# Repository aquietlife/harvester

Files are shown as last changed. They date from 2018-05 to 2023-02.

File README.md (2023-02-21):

# Harvester

Harvester in front of Pink Flowers

Harvester on grass

Harvester Profile

The Harvester is a hand-held, portable live sampler that lets you make music with everyday sounds. With the instrument, you are able to capture sounds around you (your voice, another musical instrument, environmental noises etc.). The instrument provides an interface that lets you play back the sampled sound based around a musical, pentatonic scale. This allows for a wildly expressive sonic palette that can be used for musical performance and sound art installations.

## Features

* Completely open-source software and hardware

* Audio I/O through onboard microphones, built-in speaker, and 1/4" output

* Gyroscope for 3-axis sensor input for affecting audio output

* Eight buttons for sample playbaack

* Recording button for sampling

* Looper button for simple looping

* Rechargable LiPo battery (completely portable and battery-powered!)

* Supports wall power/charging as well

## Videos

[Video of Harvester playing in snow](http://aquiet.life/assets/objects/harvester/harvester_snow.mov)

[Video of Harvester playing with gyroscope](https://drive.google.com/file/d/1DpVXfMJ-ruTxa6ZWckGBipXadZL-0WjP/view?usp=sharing)

[Video of Harvester playing in the Everglades](https://drive.google.com/file/d/1D1tRrY7IDSK8U0TIqJ7yX_h4CNaE4mdh/view?usp=share_link)

## Parts

A list of parts and costs can be found on this [Google Sheet](https://docs.google.com/spreadsheets/d/1hDYdzhToesEgNGzxmREglWhK1RFRyOljPsczHniATDo/edit?usp=sharing)

## Installation Instructions

### Solder up Harvester hat

* Full documentation TBD; The board itself has layouts for where compoenents should go!

### Install Raspian for Raspberry Pi

* Download the latest version of Raspian here: https://www.raspberrypi.org/downloads/raspbian/

* Install Raspian to your SD card. On OSX, you can use these instrucitons: https://www.raspberrypi.org/documentation/installation/installing-images/mac.md

* Whle the SD card is still connected, create a file called "ssh" in the boot directory of the card to enable SSH, e.g.:

`touch /Volumes/boot/ssh`

* Also, create a file called wpa_supplicant.conf in the boot directory

`vim /Volumes/boot/wpa_supplicant.conf `

* And add the following lines, replacing MySSID and MyPassword with you WiFi's network name and password:

```
ctrl_interface=DIR=/var/run/wpa_supplicant GROUP=netdev
update_config=1

network={ 
ssid="MySSID" 
psk="MyPassword" 
}
```

* Afterwards, plug your SD card into your RPI, power it on, and try to SSH into it:

`ssh pi@raspberrypi.local`

The password is `raspberry`

Then run the following command to set up your RPI to keep SSH on:

`sudo raspi-config`

Most importantly, go to Interfacing Options > SSH and enable SSH!

Select finish, then your RPi will reboot. Try connecting again and if everything is working, move on to the next section :D

### Set up Harvester Hat Hardware

** Part 1 **

* On your RPi, clone this repo

`git clone https://github.com/aquietlife/harvester`

At this point, it would probably be nice to install vim ;)

`sudo apt-get install vim`

Turn on i2s support in /boot/config.txt

`sudo vim /boot/config.txt`

Uncomment the following lines:

#dtparam=i2s=on 

#dtparam=i2c_arm=on 

#dtparam=spi=on 

#dtparam=audio=on 

Also add the following new entry:

`dtparam=i2c_vc=on`

Override bcm2708.vc_i2c_override in cmdline.txt

`sudo vim /boot/cmdline.txt`

Add the following line at the end of the line with a space after the word "consoles": 

`bcm2708.vc_i2c_override=1`

Finally enabled i2c arm from `raspi-config`

Then reboot your RPi

** Part 2 **

Start your Pi and move into the audio configuration scripts: 

`cd ~/harvester/software/custom-voice-hat/audio-config/scripts/`

Make the scripts executable: 

`sudo chmod +x ./custom-voice-hat.sh`

`sudo chmod +x ./install-i2s.sh`

Run the Executable scripts:

`sudo ./custom-voice-hat.sh`

`sudo ./install-i2s.sh` 

Run the custom-voice-hat.sh script again until you get .bak notification. 

`sudo ./custom-voice-hat.sh`

Reboot!

### Test Audio and Microphone

Test your audio:

* sudo aplay /usr/share/sounds/alsa/Front_Center.wav

Test your microphones:

* sudo arecord test.wav

* sudo aplay test.wav

### Install Python OSC server

* Install pyOSC

`pip install pyosc` 

You might also need to run it as:

`pip2 install pyosc`

### Install Pd

* Install Pd

`sudo apt-get install pd-comport`

`git clone git://github.com/umlaeute/pd-iemnet.git`

`cd pd-iemnet`

`make`

`sudo make install`

`cd ..`

* Install Pd libraries

`wget http://puredata.info/downloads/osc/releases/0.1/OSC-0.1.tar.gz`

`tar -xzvf OSC-0.1.tar.gz`

`cd OSC-0.1/`

`make`

`sudo make install`

`cd ..`

`wget http://puredata.info/downloads/osc/releases/0.2/osc-0.2.tar.gz`

`tar -xzvf osc-0.2.tar.gz`

`cd osc-0.2/`

`make`

`sudo make install`

`cd ..`
### Install Harvester Software

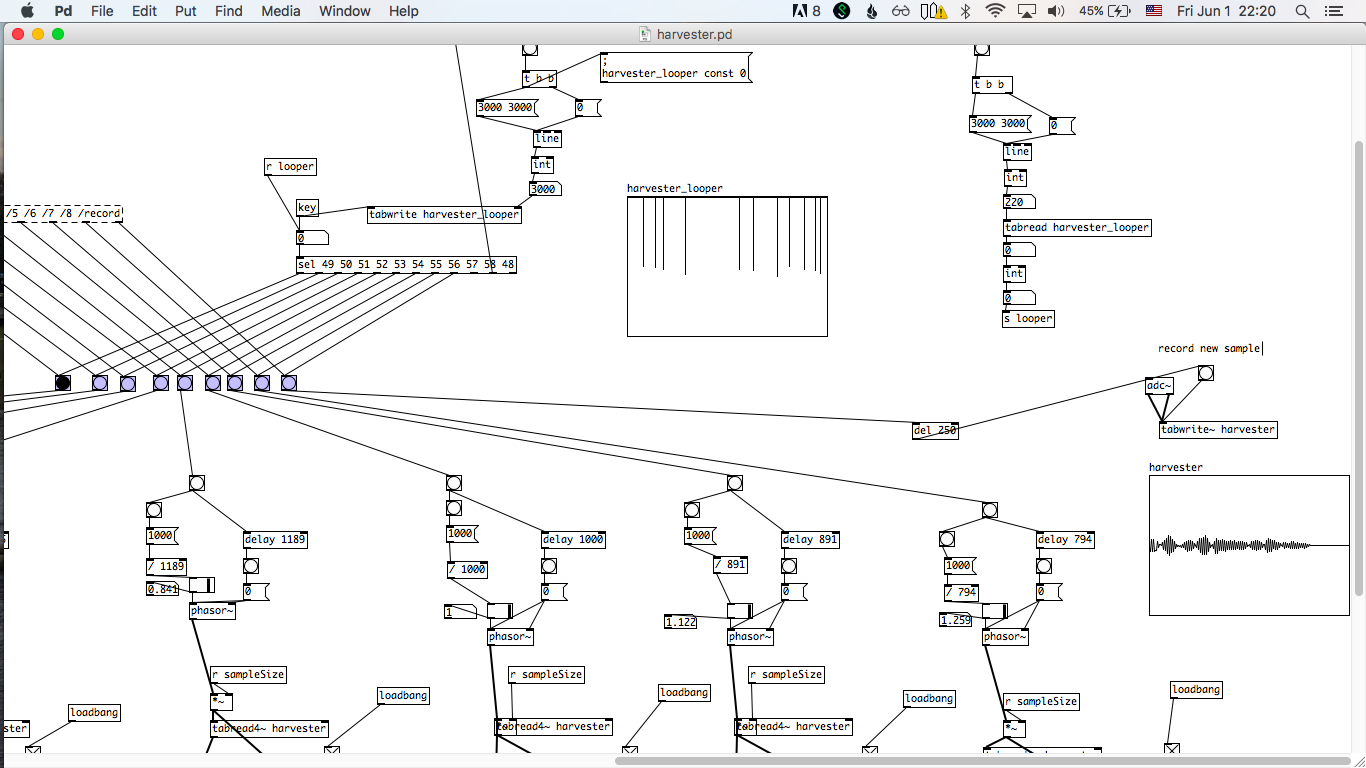
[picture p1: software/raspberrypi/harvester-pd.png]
Harvester Pd Software


* Install this repo

* Test scripts manually

`python harvester/software/raspberrypi/gpio-osc.py &`

`pd -stderr -nogui -verbose -audiodev 4 harvester/software/raspberrypi/harvester.pd &`

* Celebrate!

### Autostart software

Add the following lines to the bottom of /home/pi/.bashrc

`vim /home/pi/.bashrc`

```
if pgrep -x "python" > /dev/null
then
    echo "Python is already runnning"
else
    echo "Python is not running, attempting to run Python"
	python harvester/software/raspberrypi/gpio-osc.py >/dev/null 2>&1 &
fi

if pgrep -x "pd" > /dev/null
then
    echo "Pd is already running"
else
    echo "Pd is not running, attempting to run Pd"
	pd -stderr -nogui -verbose -audiodev 4 harvester/software/raspberrypi/harvester.pd >/dev/null 2>&1 &
fi
```

## References

### Setting up Raspberry Pi

* https://desertbot.io/blog/headless-raspberry-pi-3-bplus-ssh-wifi-setup

* https://styxit.com/2017/03/14/headless-raspberry-setup.html    

* http://ivanx.com/raspberrypi/

### Misc

* https://caffinc.github.io/2016/12/raspberry-pi-3-headless/

## Credits

Voice sample: Miyu Hosoi

Circuit layout: Mark Kleeb

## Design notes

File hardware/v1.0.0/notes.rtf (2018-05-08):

- panel mounted switch
- account for space in the enclosure for speaker and battery
- use raspberry pi for guidance on where to place things (don't put dc jack on top of usb ports, etc.)
- get standoffs/spacers

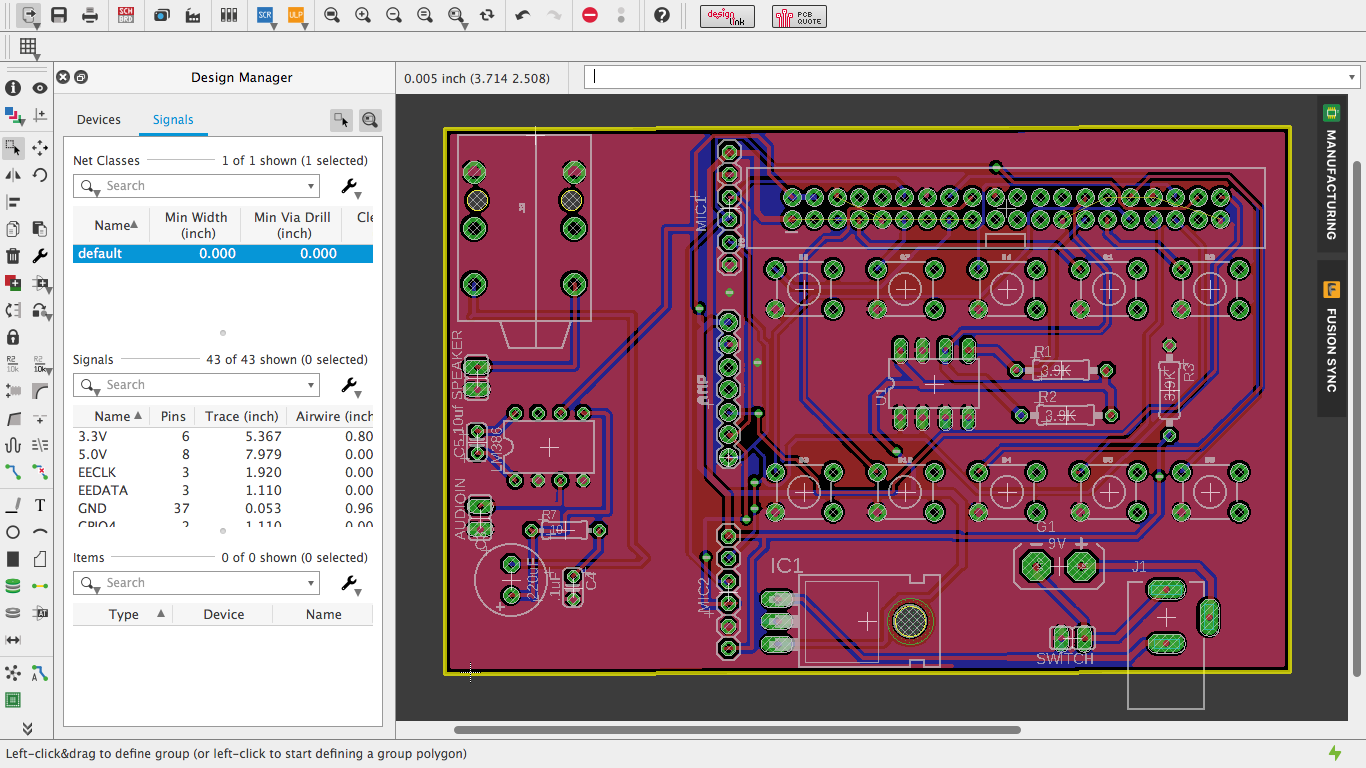
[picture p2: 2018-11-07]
hardware/v1.0.0/v1.png

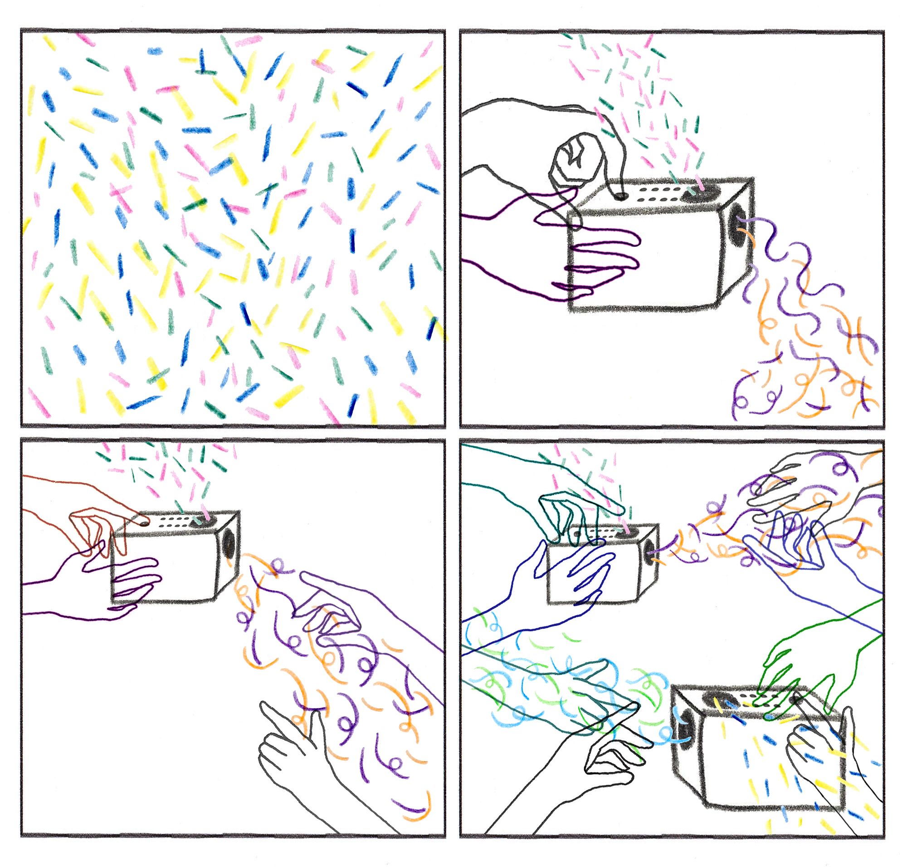
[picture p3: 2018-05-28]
harvester.jpg

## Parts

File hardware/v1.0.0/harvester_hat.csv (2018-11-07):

Part | Value | Device | Package | Description | MF | MPN | OC_FARNELL | OC_NEWARK | PROD_ID | SF_ID | SF_SKU
AMP |  | CONN_07 | 1X07 | Multi connection point. Often used as Generic Header-pin footprint for 0.1 inch spaced/style header connections
AUDIOIN |  | JP1E | JP1 | JUMPER
C3 | 220uF | CPOL-USE3.5-8 | E3,5-8 | POLARIZED CAPACITOR, American symbol
C4 | .1uF | C-US025-024X044 | C025-024X044 | CAPACITOR, American symbol
C5 | 10uf | C-US025-024X044 | C025-024X044 | CAPACITOR, American symbol
G1 | AB9V | AB9V | AB9V | 9-V BATTERY CLIP
IC1 | 7805T | 7805T | TO220H | Positive VOLTAGE REGULATOR
J1 | DCJ0202 | DCJ0202 | DCJ0202 | DC POWER JACK |  |  | unknown | unknown
J2 | AUDIO_JACK_TRS_0.25_PTH_RA" | AUDIO_JACK_TRS_0.25_PTH_RA" | AUDIO_JACK_0.25_TRS_PTH_RA" | Audio Jack, 1/4 TRS jack, horizontal, PTH, aka "Phono jack"" |  |  |  |  | CONN-12339 | COM-11144
J3 | RASPBERRYPI-40-PIN-GPIO_PTH | RASPBERRYPI-40-PIN-GPIO_PTH | 2X20_SHROUDED | Raspberry Pi GPIO Header |  |  |  |  | CONN-12263 | PRT-13054
LM386 | LM386 | LM386N-1 | DIL08 | Low Voltage Audio Power Amplifier
MIC1 |  | PINHD-1X6 | 1X06 | PIN HEADER
MIC2 |  | PINHD-1X6 | 1X06 | PIN HEADER
R1 | 3.9K | R-US_0207/10 | 0207/10 | RESISTOR, American symbol
R2 | 3.9K | R-US_0207/10 | 0207/10 | RESISTOR, American symbol
R3 | 3.9K | R-US_0207/10 | 0207/10 | RESISTOR, American symbol
R7 | 10 | R-US_0204/7 | 0204/7 | RESISTOR, American symbol
S1 | MOMENTARY-SWITCH-SPST-PTH-6.0MM | MOMENTARY-SWITCH-SPST-PTH-6.0MM | TACTILE_SWITCH_PTH_6.0MM | Momentary Switch (Pushbutton) - SPST |  |  |  |  | SWCH-08441 |  | COM-00097
S2 | MOMENTARY-SWITCH-SPST-PTH-6.0MM | MOMENTARY-SWITCH-SPST-PTH-6.0MM | TACTILE_SWITCH_PTH_6.0MM | Momentary Switch (Pushbutton) - SPST |  |  |  |  | SWCH-08441 |  | COM-00097
S3 | MOMENTARY-SWITCH-SPST-PTH-6.0MM | MOMENTARY-SWITCH-SPST-PTH-6.0MM | TACTILE_SWITCH_PTH_6.0MM | Momentary Switch (Pushbutton) - SPST |  |  |  |  | SWCH-08441 |  | COM-00097
S4 | MOMENTARY-SWITCH-SPST-PTH-6.0MM | MOMENTARY-SWITCH-SPST-PTH-6.0MM | TACTILE_SWITCH_PTH_6.0MM | Momentary Switch (Pushbutton) - SPST |  |  |  |  | SWCH-08441 |  | COM-00097
S5 | MOMENTARY-SWITCH-SPST-PTH-6.0MM | MOMENTARY-SWITCH-SPST-PTH-6.0MM | TACTILE_SWITCH_PTH_6.0MM | Momentary Switch (Pushbutton) - SPST |  |  |  |  | SWCH-08441 |  | COM-00097
S6 | MOMENTARY-SWITCH-SPST-PTH-6.0MM | MOMENTARY-SWITCH-SPST-PTH-6.0MM | TACTILE_SWITCH_PTH_6.0MM | Momentary Switch (Pushbutton) - SPST |  |  |  |  | SWCH-08441 |  | COM-00097
S7 | MOMENTARY-SWITCH-SPST-PTH-6.0MM | MOMENTARY-SWITCH-SPST-PTH-6.0MM | TACTILE_SWITCH_PTH_6.0MM | Momentary Switch (Pushbutton) - SPST |  |  |  |  | SWCH-08441 |  | COM-00097
S8 | MOMENTARY-SWITCH-SPST-PTH-6.0MM | MOMENTARY-SWITCH-SPST-PTH-6.0MM | TACTILE_SWITCH_PTH_6.0MM | Momentary Switch (Pushbutton) - SPST |  |  |  |  | SWCH-08441 |  | COM-00097
S9 | MOMENTARY-SWITCH-SPST-PTH-6.0MM | MOMENTARY-SWITCH-SPST-PTH-6.0MM | TACTILE_SWITCH_PTH_6.0MM | Momentary Switch (Pushbutton) - SPST |  |  |  |  | SWCH-08441 |  | COM-00097
S10 | MOMENTARY-SWITCH-SPST-PTH-6.0MM | MOMENTARY-SWITCH-SPST-PTH-6.0MM | TACTILE_SWITCH_PTH_6.0MM | Momentary Switch (Pushbutton) - SPST |  |  |  |  | SWCH-08441 |  | COM-00097
SPEAKER |  | JP1E | JP1 | JUMPER
SWITCH | SWITCH | JP1E | JP1 | JUMPER
U1 | CAT24C32 | AT24CP | DIL08 | 2-wire serial EEPROM |  | AT24C1024BW-SH-B | 1362646 | 03P2044

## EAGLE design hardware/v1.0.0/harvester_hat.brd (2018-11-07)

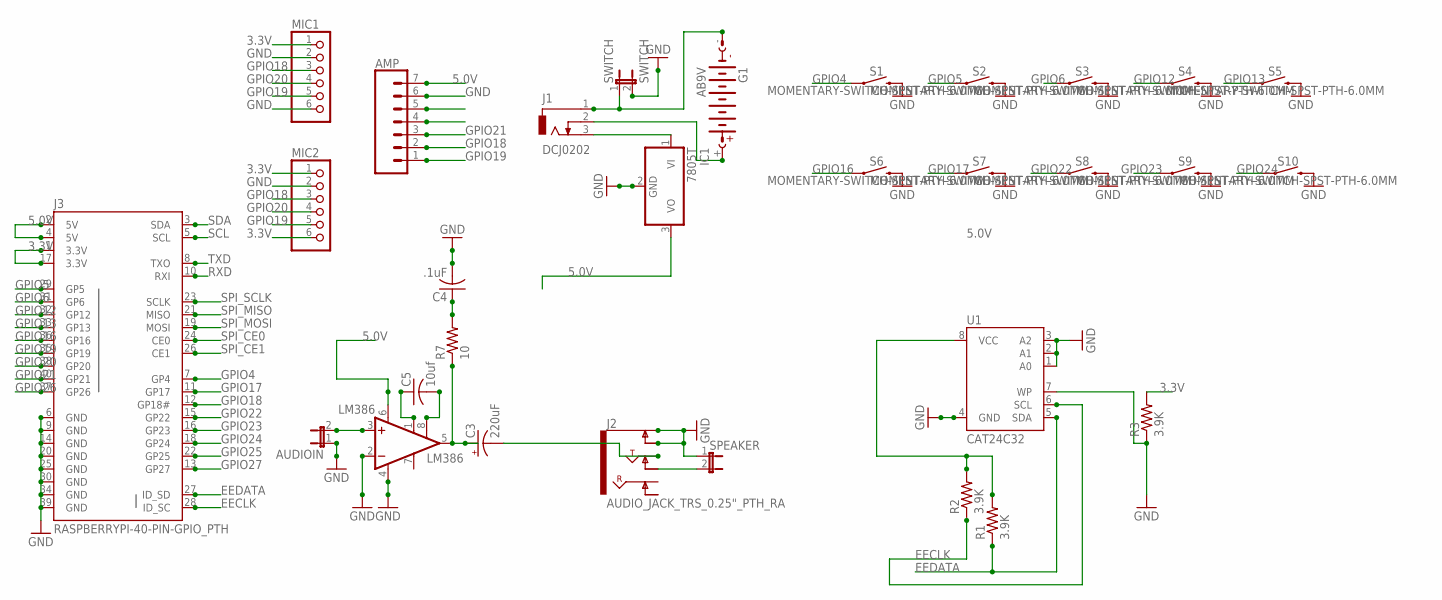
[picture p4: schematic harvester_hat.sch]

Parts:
AMP: CONN_07; 1X07
AUDIOIN: JP1E; JP1
C3: 220uF; E3,5-8
C4: .1uF; C025-024X044
C5: 10uf; C025-024X044
G1: AB9V
IC1: 7805T; TO220H
J1: DCJ0202
J2: AUDIO_JACK_TRS_0.25"_PTH_RA; AUDIO_JACK_0.25"_TRS_PTH_RA
J3: RASPBERRYPI-40-PIN-GPIO_PTH; 2X20_SHROUDED
LM386: LM386; DIL08
MIC1, MIC2: PINHD-1X6; 1X06
R1, R2, R3: 3.9K; 0207/10
R7: 10; 0204/7
S1, S2, S3, S4, S5, S6, S7, S8, S9, S10: MOMENTARY-SWITCH-SPST-PTH-6.0MM; TACTILE_SWITCH_PTH_6.0MM
SPEAKER: JP1E; JP1
SWITCH: SWITCH; JP1
U1: CAT24C32; DIL08

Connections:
3.3V: J3.1 (3.3V), J3.17 (3.3V), MIC1.1, MIC2.1, MIC2.6, R3.2
5.0V: AMP.7, IC1.3 (VO), J3.2 (5V), J3.4 (5V), LM386.6 (VS), R1.2, R2.2, U1.8 (VCC)
EECLK: J3.28 (ID_SC), R2.1, U1.6 (SCL)
EEDATA: J3.27 (ID_SD), R1.1, U1.5 (SDA)
GND: AMP.6, AUDIOIN.1, C4.2, IC1.2 (GND), J2.SLEEVE (EARTH), J2.SLEEVE-NORM (EARTH-NORM), J3.6 (GND), J3.9 (GND), J3.14 (GND), J3.20 (GND), J3.25 (GND), J3.30 (GND), J3.34 (GND), J3.39 (GND), LM386.2 (-IN), LM386.4 (GND), MIC1.2, MIC1.6, MIC2.2, R3.1, S1.3 (2), S2.3 (2), S3.3 (2), S4.3 (2), S5.3 (2), S6.3 (2), S7.3 (2), S8.3 (2), S9.3 (2), S10.3 (2), SPEAKER.1, SWITCH.2, U1.1 (A0), U1.2 (A1), U1.3 (A2), U1.4 (GND), U1.7 (WP)
GPIO4: J3.7 (GP4), S1.1
GPIO5: J3.29 (GP5), S2.1
GPIO6: J3.31 (GP6), S3.1
GPIO12: J3.32 (GP12), S4.1
GPIO13: J3.33 (GP13), S5.1
GPIO16: J3.36 (GP16), S6.1
GPIO17: J3.11 (GP17), S7.1
GPIO18: AMP.2, J3.12 (GP18#), MIC1.3, MIC2.3
GPIO19: AMP.1, J3.35 (GP19), MIC1.5, MIC2.5
GPIO20: J3.38 (GP20), MIC1.4, MIC2.4
GPIO21: AMP.3, J3.40 (GP21)
GPIO22: J3.15 (GP22), S8.1
GPIO23: J3.16 (GP23), S9.1
GPIO24: J3.18 (GP24), S10.1
GPIO25: J3.22 (GP25)
GPIO26: J3.37 (GP26)
GPIO27: J3.13 (GP27)
unnamed: G1.+, J1.2
unnamed: G1.-, J1.1, SWITCH.1
unnamed: IC1.1 (VI), J1.3
unnamed: AUDIOIN.2, LM386.3 (+IN)
unnamed: C5.1, LM386.1 (GAIN)
unnamed: J2.TIP-NORM, SPEAKER.2
unnamed: C3.-, J2.TIP
unnamed: C3.+, LM386.5 (OUT), R7.1
unnamed: C4.1, R7.2
unnamed: C5.2, LM386.8 (GAIN)
RXD: J3.10 (RXI)
SCL: J3.5 (SCL)
SDA: J3.3 (SDA)
SPI_CE0: J3.24 (CE0)
SPI_CE1: J3.26 (CE1)
SPI_MISO: J3.21 (MISO)
SPI_MOSI: J3.19 (MOSI)
SPI_SCLK: J3.23 (SCLK)
TXD: J3.8 (TXO)

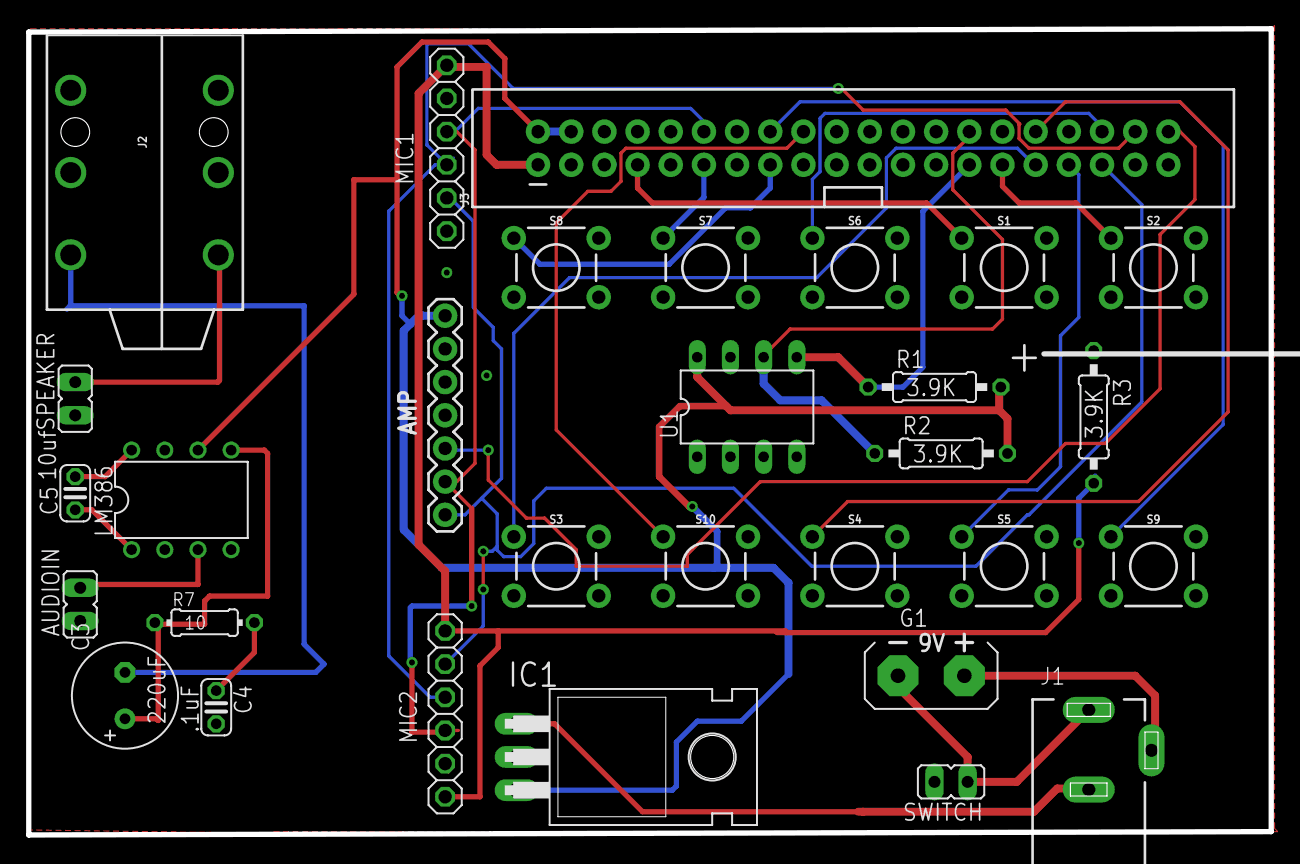
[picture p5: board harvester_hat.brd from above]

Board: 2 copper layers, 95.1 x 61.7 mm, 30 parts (0 on the bottom side), 29 nets.

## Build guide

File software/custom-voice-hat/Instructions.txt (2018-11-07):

# Parts List
1. Adafruit I2S MEMS Microphone Breakout - SPH0645LM4H - 2Nos - https://www.adafruit.com/product/3421
2. Adafruit I2S 3W Class D Amplifier Breakout - MAX98357A - 1No - https://www.adafruit.com/product/3006
3. Adafruit Perma-Proto HAT for Pi Mini Kit - With EEPROM - 1No - https://www.adafruit.com/product/2314

# Following steps to be completed on the Pi.

#Clone the project onto the pi
git clone https://github.com/shivasiddharth/custom-voice-hat

1. Turn on i2s support in /boot/config.txt with:
sudo nano /boot/config.txt

****Uncomment the following****
#dtparam=i2s=on
#dtparam=i2c_arm=on
#dtparam=spi=on
#dtparam=audio=on

****Add the following new entry****
dtparam=i2c_vc=on

Save Exit and Reboot.

2. Check for the Hats folder:
cd /proc/device-tree/

3. Open a new terminal and change directory to eepromutils:
cd /home/pi/custom-voice-hat/eepromutils

4. Make the EEPROM flasher executable and Flash the EEPROM with the eeprom file:
sudo chmod +x ./eepflash.sh
sudo ./eepflash.sh -w -f=voicehat.eep -t=24c32

5. Update raspberry pi kernels:
sudo apt-get update
sudo apt-get install raspberrypi-kernel

6. Reboot
sudo reboot

7. Check if your HAT is recognized,:
cd /proc/device-tree/

***YOU WILL HAVE A HAT FOLDER NOW WITH VOICE HAT DETAILS***

# Shutdown and Wire the Parts as indicated in the attached wiring diagram
***CAUTION- Amplifier board should be powered using 5V and the Mics using 3.3v***

# Start your Pi and move into the audio configuration scripts:
cd /home/pi/custom-voice-hat/audio-config/scripts/

#Make the scripts executable:
sudo chmod +x ./custom-voice-hat.sh
sudo chmod +x ./install-i2s.sh

#Run the Executable scripts
sudo ./custom-voice-hat.sh
sudo ./install-i2s.sh

****RUN THE custom-voice-hat.sh script untill you get .bak notification****
****REBOOT and Enjoy your HAT****

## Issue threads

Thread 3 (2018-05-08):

Design enclosure

johanndiedrick, 2018-05-08:
- [ ] account for space in the enclosure for speaker and battery
- [ ] use raspberry pi for guidance on where to place things (don't put dc jack on top of usb ports, etc.)
- [ ] get standoffs/spacers

Closed 2021-04-12.

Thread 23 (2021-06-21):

Issue with using GPIO pin 16 in Node

georgemandis, 2021-06-21:
# The Issue

If you try to watch GPIO pin 16 in Node using the [`onoff` npm package](https://www.npmjs.com/package/onoff) I get the following error message:

```
Error: EBUSY: resource busy or locked, write.
```

You can find the Node code in this PR at the moment:
https://github.com/aquietlife/harvester/pull/22

# What I've Tried

I've stopped PureData and the Python script from running on the Pi. I've also updated .bashrc so it doesn't restart those things every time I reboot. All of the other buttons work perfectly—just not button 7 (pin 16)!

I took a look at the pins and noticed pin 16 appeared to be setup as an OUT instead of an IN like the other pins that map to buttons were:
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

I found this thread, which seems to also involve an issue specific to this pin and the RaspberryPi: https://www.raspberrypi.org/forums/viewtopic.php?t=135813.

I ran `rpi-update` to update to the latest firmware to 40064f62df458d0a56a8a17c9168d7529372099a. This seemed to fix the issue for people on the thread, but did not see any changes.

Then I tried running this commend to change the pin to an IN type, which seemed promising.

```
---> raspi-gpio set 16 ip pu
```

I ran `gpio readall` again and I saw the pin updated as I'd hoped/expected:
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

At this point I rebooted the Pi, double-checked to make sure my GPIO settings had kept, and tried it again.

Still no luck :-/

It's curious that it does not fail in Python. I'm wondering if the resource is truly busy and Python simply doesn't care?

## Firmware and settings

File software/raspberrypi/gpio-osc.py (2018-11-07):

# External module imports
import RPi.GPIO as GPIO
import time
import OSC

#client setup
c = OSC.OSCClient()

#local host: port 9001
c.connect(('127.0.0.1', 9001))

# Pin Definitons:
button1 = 6
button2 = 24
button3 = 12
button4 = 13
button5 = 22
button6 = 17
button7 = 16
button8 = 4
buttonRecord = 23
buttonLoop = 5

# Pin Setup:
GPIO.setmode(GPIO.BCM) # Broadcom pin-numbering scheme
GPIO.setup(button1, GPIO.IN, pull_up_down=GPIO.PUD_UP) # Button pin set as input w/ pull-up
GPIO.setup(button2, GPIO.IN, pull_up_down=GPIO.PUD_UP) # Button pin set as input w/ pull-up
GPIO.setup(button3, GPIO.IN, pull_up_down=GPIO.PUD_UP) # Button pin set as input w/ pull-up
GPIO.setup(button4, GPIO.IN, pull_up_down=GPIO.PUD_UP) # Button pin set as input w/ pull-up
GPIO.setup(button5, GPIO.IN, pull_up_down=GPIO.PUD_UP) # Button pin set as input w/ pull-up
GPIO.setup(button6, GPIO.IN, pull_up_down=GPIO.PUD_UP) # Button pin set as input w/ pull-up
GPIO.setup(button7, GPIO.IN, pull_up_down=GPIO.PUD_UP) # Button pin set as input w/ pull-up
GPIO.setup(button8, GPIO.IN, pull_up_down=GPIO.PUD_UP) # Button pin set as input w/ pull-up
GPIO.setup(buttonRecord, GPIO.IN, pull_up_down=GPIO.PUD_UP) # Button pin set as input w/ pull-up
GPIO.setup(buttonLoop, GPIO.IN, pull_up_down=GPIO.PUD_UP) # Button pin set as input w/ pull-up

print("Here we go! Press CTRL+C to exit")
try:
	while True:
            if GPIO.input(button1) == False:
                msg = OSC.OSCMessage()
                msg.setAddress("/1")
                msg.append("button1")
                c.send(msg)
        	print('Button 1 Pressed')
        	time.sleep(0.2)
            elif GPIO.input(button2) == False:
                msg = OSC.OSCMessage()
                msg.setAddress("/2")
                msg.append("button2")
                c.send(msg)
        	print('Button 2 Pressed')
        	time.sleep(0.2)
            elif GPIO.input(button3) == False:
                msg = OSC.OSCMessage()
                msg.setAddress("/3")
                msg.append("button3")
                c.send(msg)
        	print('Button 3 Pressed')
        	time.sleep(0.2)
            elif GPIO.input(button4) == False:
                msg = OSC.OSCMessage()
                msg.setAddress("/4")
                msg.append("button4")
                c.send(msg)
        	print('Button 4 Pressed')
        	time.sleep(0.2)
            elif GPIO.input(button5) == False:
                msg = OSC.OSCMessage()
                msg.setAddress("/5")
                msg.append("button5")
                c.send(msg)
        	print('Button 5 Pressed')
        	time.sleep(0.2)
            elif GPIO.input(button6) == False:
                msg = OSC.OSCMessage()
                msg.setAddress("/6")
                msg.append("button6")
                c.send(msg)
        	print('Button 6 Pressed')
        	time.sleep(0.2)
            elif GPIO.input(button7) == False:
                msg = OSC.OSCMessage()
                msg.setAddress("/7")
                msg.append("button7")
                c.send(msg)
        	print('Button 7 Pressed')
        	time.sleep(0.2)
            elif GPIO.input(button8) == False:
                msg = OSC.OSCMessage()
                msg.setAddress("/8")
                msg.append("button8")
                c.send(msg)
        	print('Button 8 Pressed')
        	time.sleep(0.2)
            elif GPIO.input(buttonRecord) == False:
                msg = OSC.OSCMessage()
                msg.setAddress("/record")
                msg.append("record")
                c.send(msg)
        	print('Button Record Pressed')
        	time.sleep(0.2)
            elif GPIO.input(buttonLoop) == False:
                msg = OSC.OSCMessage()
                msg.setAddress("/loop")
                msg.append("loop")
                c.send(msg)
        	print('Button Loop Pressed')
        	time.sleep(0.2)

except KeyboardInterrupt: # If CTRL+C is pressed, exit cleanly:
    GPIO.cleanup() # cleanup all GPIO

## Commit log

2018-05-08 added hardware eagle files
    [harvester_hat.brd, harvester_hat.sch]
2018-06-02 added extra files
    [harvester_hat.brd, harvester_hat.sch]
2018-11-07 updated gitignore, hardware and hat software
    [harvester_hat.brd, harvester_hat.csv, harvester_hat.sch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]

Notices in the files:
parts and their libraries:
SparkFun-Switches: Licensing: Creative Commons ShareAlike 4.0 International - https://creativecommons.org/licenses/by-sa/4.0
